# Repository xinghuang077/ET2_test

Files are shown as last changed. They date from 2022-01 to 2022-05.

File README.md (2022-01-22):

## ET2_test chip test
  - ET2_test chip test document, python code and firmware code.

  - ET2 has four circutry blocks including dedicated Inter-Integrated Circuit (I2C), Time-to-Digital Converter (TDC), Electrical Fuse (E-Fuse), and Temperature Sensor (TS). These blocks will be used in the coming ETROC2 chip. They should be fully tested and give the confidence to reuse or entend in ETROC2 chip.

## File organization
  - The repository is used to store the test document and the test code for recording and sharing. The code includes the python code communicated with I2C and the firmware for the TDC test.

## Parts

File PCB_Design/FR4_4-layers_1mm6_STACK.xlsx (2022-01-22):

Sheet: PLOECH
4-layer 搭叠， 表面处理化金5U”/镍150U”
 |  |  |  |  | SINGLE ENDED |  | EDGE COUPLED DEFFERENTIAL
Layer |  | Material | Thickness | ER | WIDTH | TARGET INPEDANCE | WIDTH | GAP | TARGET INPEDANCE
 |  | soldermask | 0.7 mil
L1 | TOP | Cu+Plating | 1.4 mil |  | 5.0 mil | 50 OHM | 4.0 mil | 7.0 mil | 100 OHM
 |  | FR4 | 3.1 mil
L2 | GND | Cu | 1.3 mil
 |  | FR4 | 50.0 mil
L3 | VCC | Cu | 1.3 mil
 |  | FR4 | 3.1 mil
L4 | BOTTOM | Cu+Plating | 1.4 mil |  | 5.0 mil | 50 OHM | 4.0 mil | 7.0 mil | 100 OHM
 |  | soldermask | 0.7 mil
 |  | Total thickness | 63.0 mil |  | 1.6mm +/- 10%
 |  |  | 1.6002

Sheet: Sheet1
8-layer 搭叠， 表面处理化金5U”/镍150U”
 |  |  |  | SINGLE ENDED |  | EDGE COUPLED DEFFERENTIAL
Layer |  | Material | Thickness | WIDTH | TARGET INPEDANCE | WIDTH | GAP | TARGET INPEDANCE
 |  | soldermask | 0.7 mil
L1 | TOP | Cu+Plating | 1.4 mil | 5 MIL | 50 OHM | 4.0 mil | 8 MIL | 100 OHM
 |  | FR4 | 3.2 mil
L2 | VCC1 | Cu | 1.2 mil
 |  | FR4 | 7.5 mil
L3 | SIG1 | Cu | 1.2 mil | 4.9 mil | 50 OHM | 4.0 mil | 8.0 mil | 100 OHM
 |  | FR4 | 7.5 mil
L4 | VCC2 | Cu | 1.2 mil
 |  | FR4 | 13.0 mil
L5 | GND | Cu | 1.2 mil
 |  | FR4 | 7.5 mil
L6 | SIG2 | Cu | 1.2 mil | 4.9 mil | 50 OHM | 4.0 mil | 8.0 mil | 100 OHM
 |  | FR4 | 7.5 mil
L7 | VCC3 | Cu | 1.2 mil
 |  | FR4 | 3.2 mil
L8 | BOTTOM | Cu+Plating | 1.4 mil | 5 MIL | 50 OHM | 4.0 mil | 8 MIL | 100 OHM
 |  | soldermask | 0.7 mil
 |  | Total thickness | 60.8 mil
4-layer 搭叠， 表面处理化金5U”/镍150U”
 |  |  |  | SINGLE ENDED |  | EDGE COUPLED DEFFERENTIAL
Layer |  | Material | Thickness | WIDTH | TARGET INPEDANCE | WIDTH | GAP | TARGET INPEDANCE
 |  | soldermask | 0.7 mil
L1 | TOP | Cu+Plating | 1.4 mil | 10 MIL | 50 OHM | 5.0 mil | 5.2 mil | 100 OHM
 |  | FR4 | 6.0 mil
L2 | GND | Cu | 1.2 mil
 |  | FR4 | 38.0 mil
L3 | VCC | Cu | 6.0 mil
 |  | FR4 | 6.0 mil
L4 | BOTTOM | Cu+Plating | 1.4 mil | 10 MIL | 50 OHM | 5.0 mil | 5.2 mil | 100 OHM
 |  | soldermask | 0.7 mil
 |  | Total thickness | 61.4 mil

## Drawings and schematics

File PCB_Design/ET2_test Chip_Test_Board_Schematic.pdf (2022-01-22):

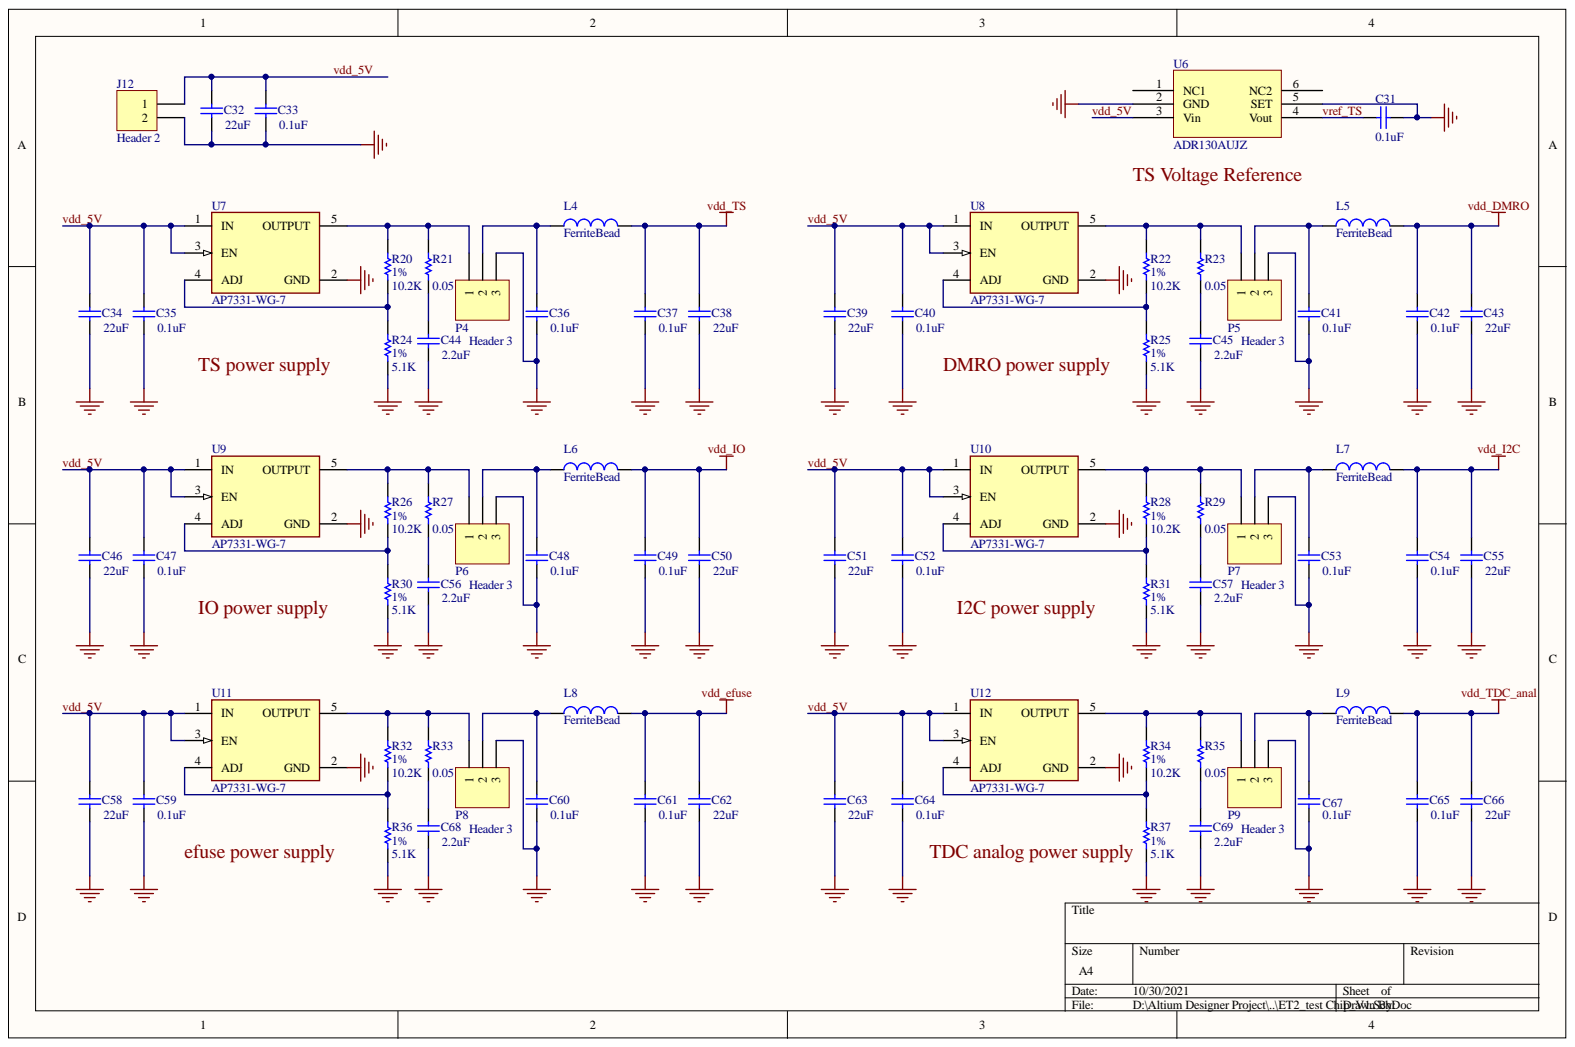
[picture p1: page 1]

Size A4 | Number | Revision

Date: 10/30/2021 | Sheet of
File: D:\Altium Designer Project\..\ET2_test Chip_V Draw1.n SBchDy: oc

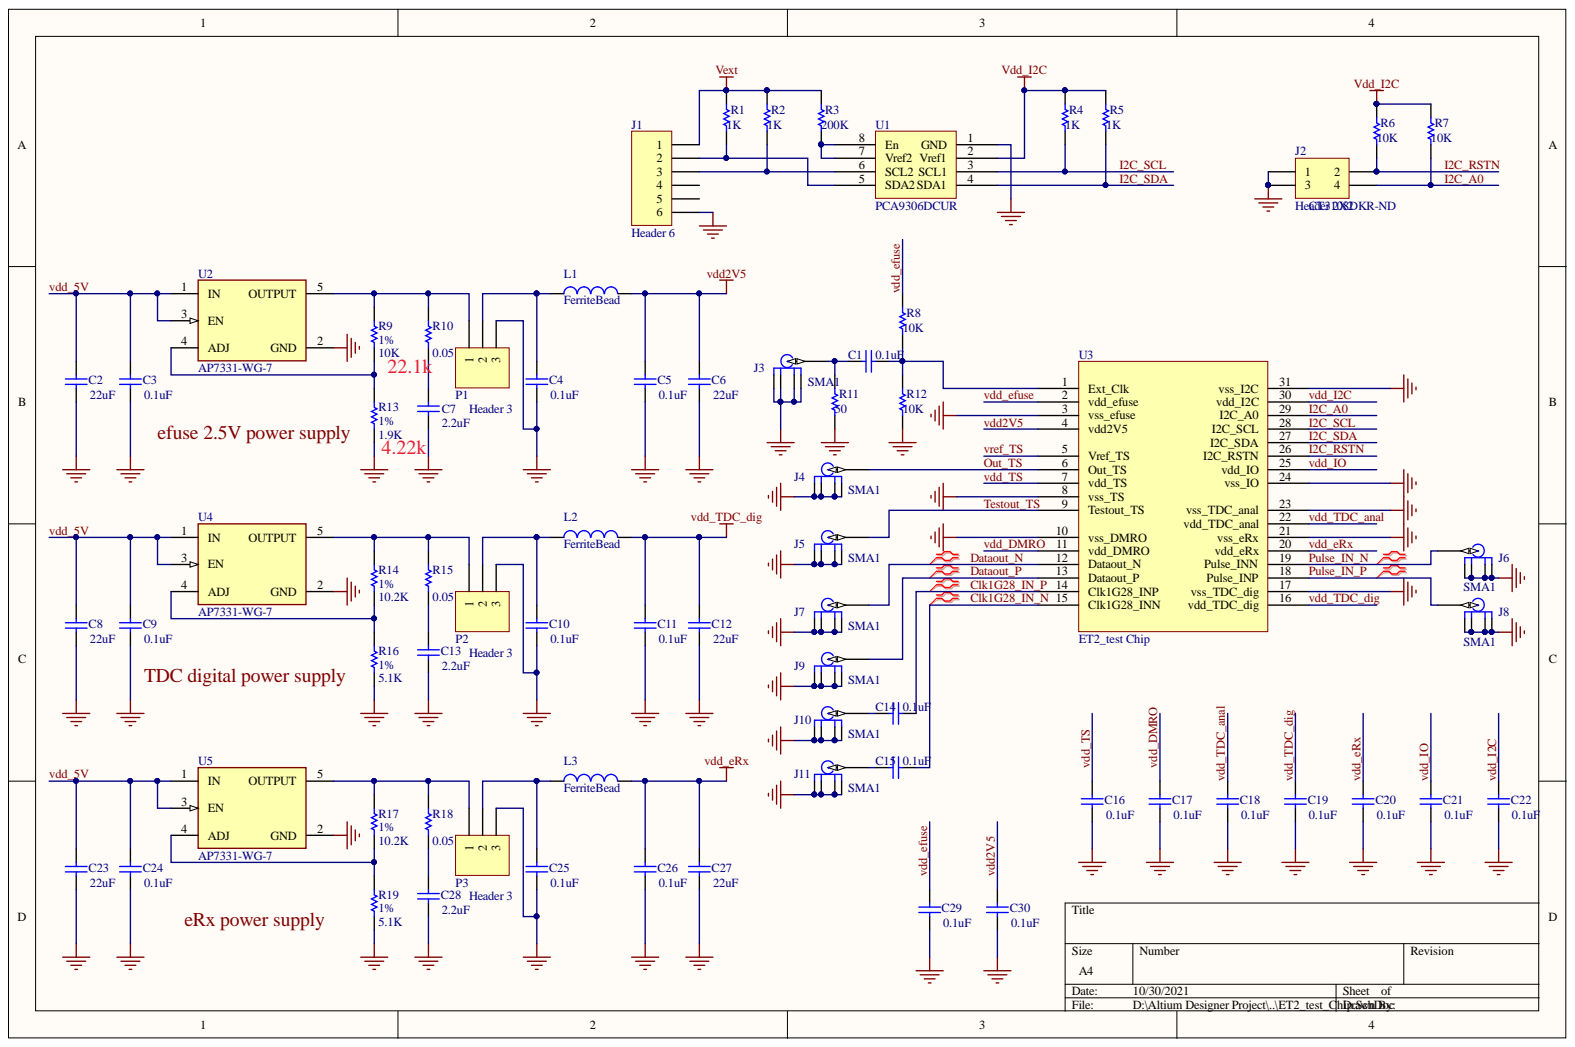
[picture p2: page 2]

Numbe r | R evision

: 10/30/2021 | She et of
File : D:\Altium D esigne r P roje ct\. .\ET2_test_Chip. Dr | aSwchDn Bocy:

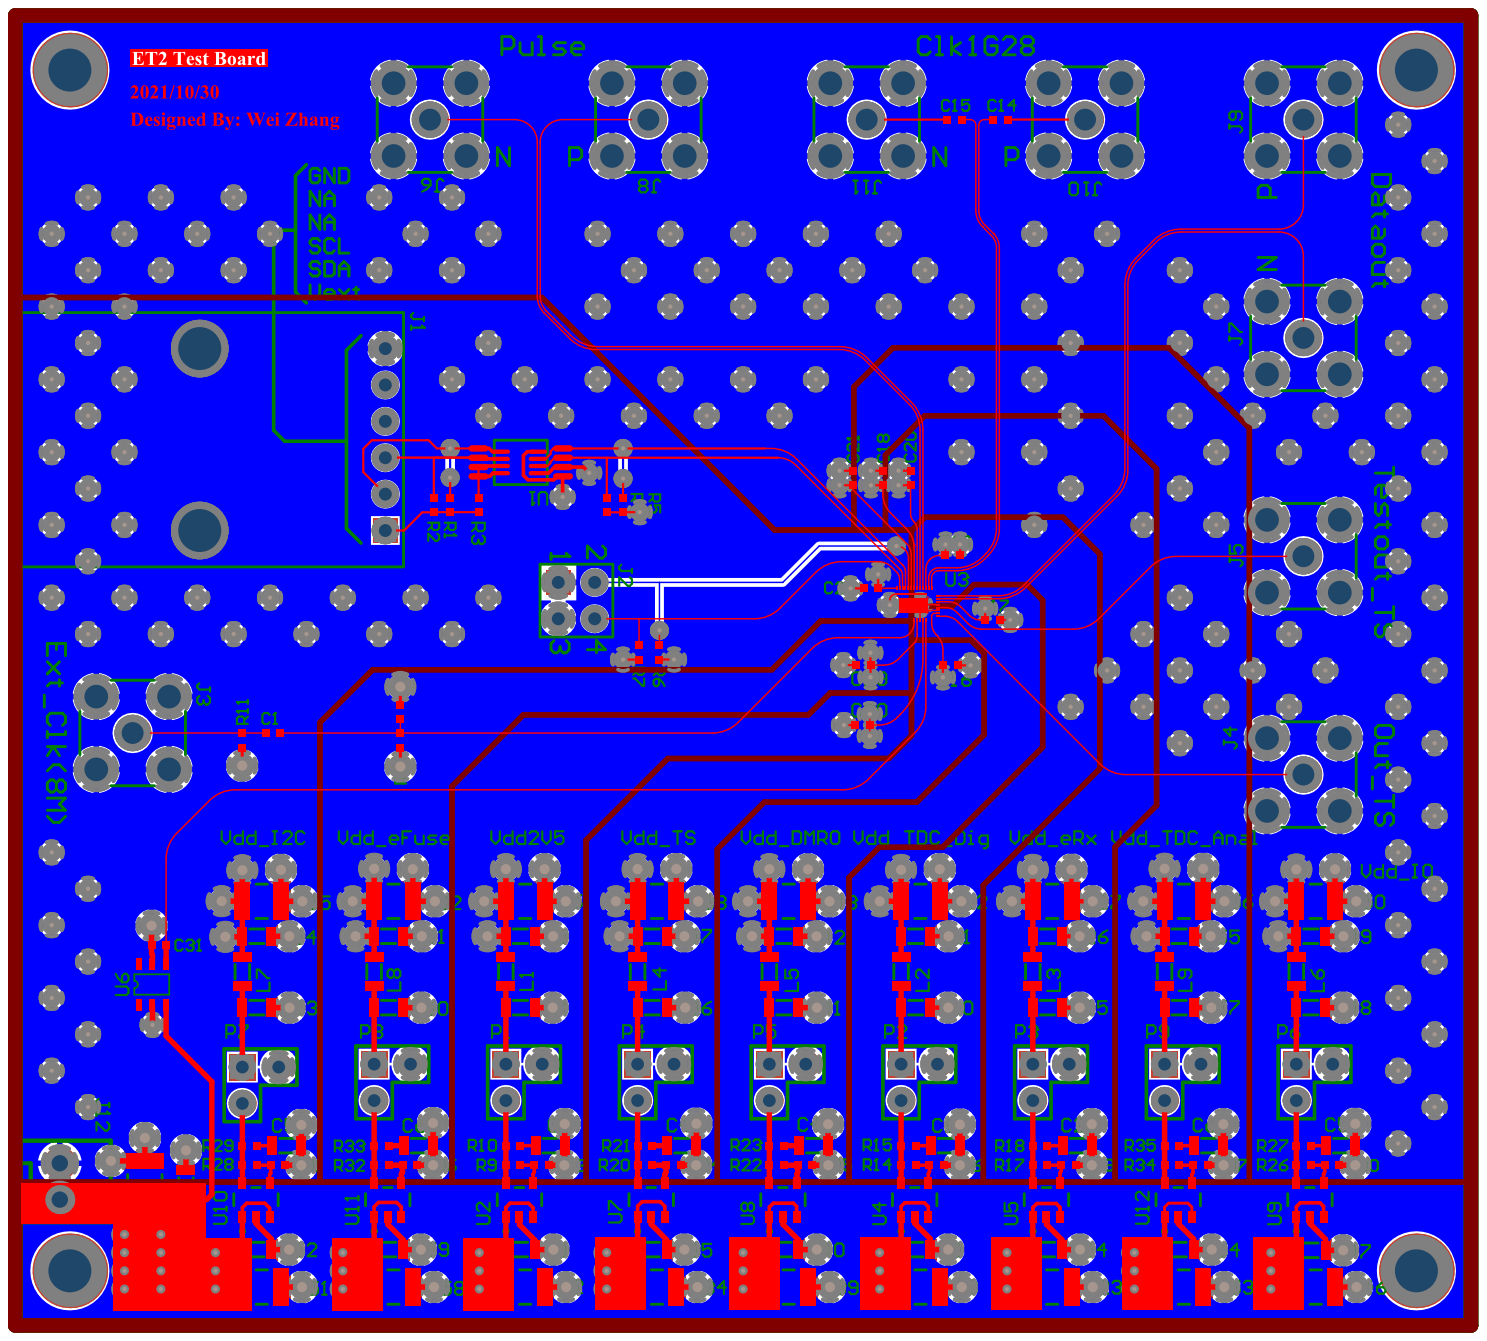
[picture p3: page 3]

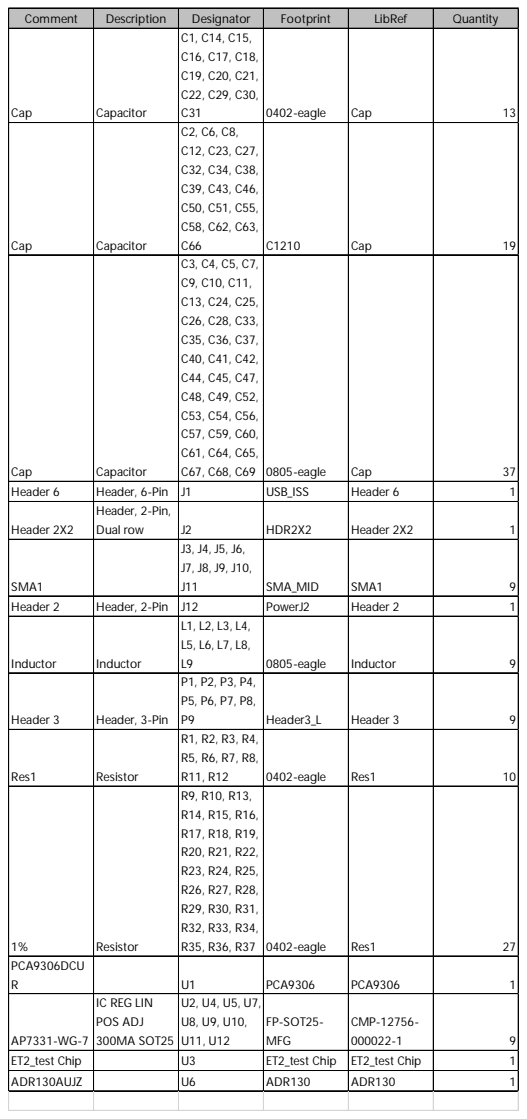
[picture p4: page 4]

Comment | Description | Designator | Footprint | LibRef | Quantity
Cap | Capacitor | C1, C14, C15, C16, C17, C18, C19, C20, C21, C22, C29, C30, C31 | 0402-eagle | Cap | 13

Cap | Capacitor | C2, C6, C8, C12, C23, C27, C32, C34, C38, C39, C43, C46, C50, C51, C55, C58, C62, C63, C66 | C1210 | Cap | 19

Cap | Capacitor | C3, C4, C5, C7, C9, C10, C11, C13, C24, C25, C26, C28, C33, C35, C36, C37, C40, C41, C42, C44, C45, C47, C48, C49, C52, C53, C54, C56, C57, C59, C60, C61, C64, C65, C67, C68, C69 | 0805-eagle | Cap | 37

Header 6 | Header, 6-Pin | J1 | USB_ISS | Header 6 | 1
Header 2X2 | Header, 2-Pin, Dual row | J2 | HDR2X2 | Header 2X2 | 1

SMA1 | | J3, J4, J5, J6, J7, J8, J9, J10, J11 | SMA_MID | SMA1 | 9

Header 2 | Header, 2-Pin | J12 | PowerJ2 | Header 2 | 1
Inductor | Inductor | L1, L2, L3, L4, L5, L6, L7, L8, L9 | 0805-eagle | Inductor | 9

Header 3 | Header, 3-Pin | P1, P2, P3, P4, P5, P6, P7, P8, P9 | Header3_L | Header 3 | 9

Res1 | Resistor | R1, R2, R3, R4, R5, R6, R7, R8, R11, R12 | 0402-eagle | Res1 | 10

1% | Resistor | R9, R10, R13, R14, R15, R16, R17, R18, R19, R20, R21, R22, R23, R24, R25, R26, R27, R28, R29, R30, R31, R32, R33, R34, R35, R36, R37 | 0402-eagle | Res1 | 27

PCA9306DCU R | | U1 | PCA9306 | PCA9306 | 1

AP7331-WG-7 | IC REG LIN POS ADJ 300MA SOT25 | U2, U4, U5, U7, U8, U9, U10, U11, U12 | FP-SOT25-MFG | CMP-12756-000022-1 | 9

ET2_test Chip | | U3 | ET2_test Chip | ET2_test Chip | 1
ADR130AUJZ | | U6 | ADR130 | ADR130 | 1

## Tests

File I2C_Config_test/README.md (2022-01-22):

USB-ISS module
-------------
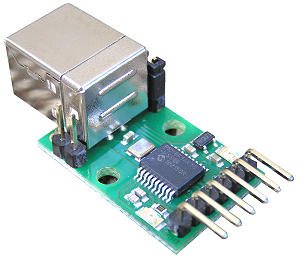
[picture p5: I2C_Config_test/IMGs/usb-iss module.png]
USB-ISS module

  - The USB-ISS  Multifunction USB Communications Module provides a complete interface between your PC and the **I2C bus**, SPI bus, a Serial port and general purpose Analogue Input or Digital I/O. The module is powered from the USB. Operating voltage is selectable between 3.3v and 5v.
  - USB-ISS document: https://www.robot-electronics.co.uk/htm/usb_iss_tech.htm
  - USB-ISS Python library: https://usb-iss.readthedocs.io
  - USB-ISS Python souce code: https://github.com/sneakypete81/usb_iss/tree/master/src/usb_iss
  - Since the operating voltage of USB-ISS module is higher than the power of ET2_test chip (1.2 V), a level translator is needed on the test PCB board to lower the logic high voltages of SDA and SCL to 1.2 V.

Usage Example
-------------
```

    from usb_iss import UsbIss, defs

    # Configure I2C mode

    iss = UsbIss()
    iss.open("COM3") # User check the PC device management for the right COM interface
    iss.setup_i2c()

    # Write and read back some data
    # NOTE: I2C methods use 7-bit device addresses (0x00 - 0x7F)
    # The example shows the register addresses is 8 bits from 0x00 to 0xFF, the USB-ISS module also support the 16-bit register addresses (0x0000 0xFFFF).
    # iss.i2c.write_ad2 for 16-bit register address writing, iss.i2c.read_ad2 for 16-bit register address reading.

    iss.i2c.write(0x62, 0, [0, 1, 2]);
    data = iss.i2c.read(0x62, 0, 3)

    print(data)
    # [0, 1, 2]
```

Installing
----------
```
    pip install usb-iss

```

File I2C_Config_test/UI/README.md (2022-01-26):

PyQt5 is a comprehensive set of Python bindings for Qt v5. PyQt5 is the latest version of a GUI widgets toolkit developed by Riverbank Computing. It is a Python interface for Qt, one of the most powerful, and popular cross-platform GUI library.

https://pypi.org/project/PyQt5/

https://www.tutorialspoint.com/pyqt5/index.htm

PyQt5 is selectd to implement UIs for different ET2_test test purposes.
This is an example for ET2_test I2C test. The simple thing is read or write one byte at one time.

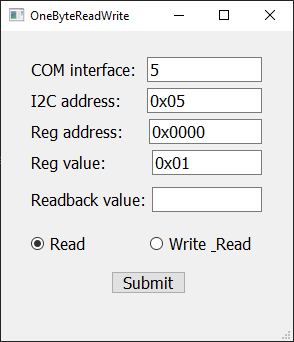
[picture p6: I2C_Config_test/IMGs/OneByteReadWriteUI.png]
ET2_test onebytereadwriteUI


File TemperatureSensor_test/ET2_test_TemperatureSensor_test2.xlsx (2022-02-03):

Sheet: Sheet1
TempSetting | TS_testOUT4 | TS_OUT4 | TS_testOUT5 | TS_OUT5 | TS_testOUT6 | TS_OUT6 | TS_testOUT7 | TS_OUT7 | TS_testOUT8 | TS_OUT8 | PT100
25 | 0.5389 | 0.5441 | 0.6075 | 0.6141 | 0.5412 | 0.5459 | 0.567 | 0.5725 | 0.496 | 0.4999 | 109.599
30 | 0.5516 | 0.5566 | 0.6211 | 0.6275 | 0.5563 | 0.5615 | 0.5803 | 0.5858 | 0.5095 | 0.5133 | 111.726
35 | 0.565 | 0.5703 | 0.6354 | 0.6426 | 0.573 | 0.5782 | 0.5944 | 0.5997 | 0.5237 | 0.5275 | 113.991
40 | 0.5778 | 0.5831 | 0.6486 | 0.6557 | 0.5874 | 0.5925 | 0.608 | 0.6136 | 0.5375 | 0.5414 | 116.092
45 | 0.5864 | 0.5923 | 0.6395 | 0.6463 | 0.5807 | 0.5855 | 0.621 | 0.6268 | 0.5499 | 0.5536 | 118.15
50 | 0.6 | 0.6056 | 0.653 | 0.6599 | 0.5954 | 0.601 | 0.6344 | 0.6401 | 0.5634 | 0.5675 | 120.295
55 | 0.612 | 0.6177 | 0.6666 | 0.6734 | 0.6103 | 0.6154 | 0.6481 | 0.6535 | 0.5768 | 0.5811 | 122.326
60 | 0.6244 | 0.6301 | 0.6784 | 0.6852 | 0.6244 | 0.6298 | 0.661 | 0.6672 | 0.591 | 0.5949 | 124.463
65 | 0.6372 | 0.6431 | 0.6914 | 0.6983 | 0.638 | 0.6439 | 0.6742 | 0.6807 | 0.604 | 0.6082 | 126.574
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

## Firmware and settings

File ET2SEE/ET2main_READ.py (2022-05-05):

# import pandas as pdc
import os
import pyvisa as visa
import sys
import time
from usb_iss import UsbIss, defs
import ET2_test_functions
import numpy as np
import datetime

'''
@author: Xing Huang
@date: Jan. 7, 2021
This script as a generic I2C cofniguration software to configure I2C slave. The I2C reg configuration data is read into a xxx.dat file.
The UsbIss as I2C master deivce is used to write and read I2C slave register.
'''


#-----------------------------------------------------------------------------------#
freqency = 1000
duration = 200
#-----------------------------------------------------------------------------------#
def main():
    user_config_filename = "ET2_Config_SEUTest.txt" ## ET2_Config_SEUTest modified the line 520, 521 for SEU test based on ET2_Config.txt
    COM_Port = "COM4"
    
    # value = input("Please enter the number of the ET2_test board you are testing:\n")

    ## All of the register addresses, and default values 
    Reg_Addr = []
    Reg_Val_Default = []
    Reg_Val_Write = []
    Reg_Val_Broadcast = []      

    ## Read configuraton file, I2C address, 16-bit register addresses, 8-bit register values
    with open(user_config_filename, 'r') as infile:                  # read configuration file
        for line in infile.readlines():
            if len(line.split()) == 1:
                #print(len(line.split()))                          # read I2C address
                I2C_Addr = int(line.split()[0], 16)
            else:                                               # read register address and value
                Reg_Addr += [int(line.split()[0], 16)]
                Reg_Val_Default += [int(line.split()[1], 16)]
                Reg_Val_Write += [int(line.split()[2], 16)]
                Reg_Val_Broadcast += [int(line.split()[3], 16)]
    print('There are', len(Reg_Addr), 'registers in ET2_test chip.')

    ## Power Supply USB devices
    VISA_ADDRESS = ET2_test_functions.find('USB?*INSTR')

    ## set usb-iss iic master device
    iss = UsbIss()
    iss.open(COM_Port)
    iss.setup_i2c(clock_khz=100)

    ## Check whether a device responds at the specified I2C address.
    if(not iss.i2c.test(I2C_Addr)):
        print("Unsuccessful communication with the target via I2C!")
        return
    print("Successful communication with the target via I2C!")

    ## Swap all register addresses in ET2_test chip.
    Reg_Addr_new = ET2_test_functions.regAddrSwap(Reg_Addr)
    # print("reg addr swapped") 
     

    while True:
       ###################################################################################################### 
       # Pixel configuration registers write and read back to compare the write-in and read-back values
       ######################################################################################################
        myAddr = []
        myreadVal = []              
        expectedVal = []
        for i in list(range(0, 8)) + list(range(120, 128)) + list(range(128, 136)) + list(range(248, 256)) + list(range(512, 524)):
            myAddr += [Reg_Addr[i]]
            expectedVal += [Reg_Val_Write[i]]
            myreadVal += iss.i2c.read_ad2(I2C_Addr, Reg_Addr_new[i], 1) 
            # print("%d %x %x" %(i, Reg_Addr[i], Reg_Val_Write[i]))
        #end for

       ######################################################################################################
       ## SEU Counter Read
       ######################################################################################################
        seuCntAddr = []
        seuCntVal = []
        for i in list(range(560, 564)):
            seuCntAddr += [Reg_Addr[i]]
            # print(hex(Reg_Addr[i]))
            seuCntVal += iss.i2c.read_ad2(I2C_Addr, Reg_Addr_new[i], 1) 
        # print("%s" %( lasttime), "SEU counter Addresses:", '[{}]'.format(', '.join(hex(x) for x in seuCntAddr)), "Values:", "%s" %( serCntVal))
        # print("%s The SEU counter in ET2_test I2C, address & value %s %s" %(lasttime, seuCntAddr, serCntVal))
        #end for


       ######################################################################################################
       ## Variable Status Read
       ######################################################################################################
        statusVarAddr = []
        statusVarReadVal = []              
        statusVarExpectedVal = []
        for i in list(range(256, 264)) + list(range(376, 392)) +  list(range(504, 512)):
        # for i in list(range(504, 512)):
            # print(hex(Reg_Addr[i]))
            statusVarAddr += [Reg_Addr[i]]
            # statusVarExpectedVal += [Reg_Val_Default[i]]
            statusVarReadVal += iss.i2c.read_ad2(I2C_Addr, Reg_Addr_new[i], 1) 
            # print("%d %x %x" %(i, Reg_Addr[i], Reg_Val_Write[i]))
            
        statusVarExpectedVal = []
        regAddr = []
        regReadVal = []
        for i in list(range(0, 8)) + list(range(120, 128)) + list(range(128, 136)) + list(range(248, 256)) + list(range(512, 520)):
            regAddr += [Reg_Addr[i]]
            regReadVal += iss.i2c.read_ad2(I2C_Addr, Reg_Addr_new[i], 1)
        # print(regReadVal[0], statusVarReadVal[0])
        statusVarExpectedVal = [regReadVal[0] ^ 0x00,  regReadVal[1] ^ 0xff,  regReadVal[2] ^ 0xff,  regReadVal[3] ^ 0xff, \
                                regReadVal[4] ^ 0xff,  regReadVal[5] ^ 0xff,  regReadVal[6] ^ 0xff,  regReadVal[7] ^ 0xff, \
                                regReadVal[8] ^ 0x0f,  regReadVal[9] ^ 0xff,  regReadVal[10] ^ 0xff, regReadVal[11] ^ 0xff, \
                                regReadVal[12] ^ 0xff, regReadVal[13] ^ 0xff, regReadVal[14] ^ 0xff, regReadVal[15] ^ 0xff, \
                                regReadVal[16] ^ 0xf0, regReadVal[17] ^ 0xff, regReadVal[18] ^ 0xff, regReadVal[19] ^ 0xff, \
                                regReadVal[20] ^ 0xff, regReadVal[21] ^ 0xff, regReadVal[22] ^ 0xff, regReadVal[23] ^ 0xff, \
                                regReadVal[24] ^ 0xff, regReadVal[25] ^ 0xff, regReadVal[26] ^ 0xff, regReadVal[27] ^ 0xff, \
                                regReadVal[28] ^ 0xff, regReadVal[29] ^ 0xff, regReadVal[30] ^ 0xff, regReadVal[31] ^ 0xff]
        # print(statusVarExpectedVal, "\n", statusVarReadVal) 
    

       ######################################################################################################
       ## Stasus Read
       ######################################################################################################
        statusAddr = []
        statusReadVal = []              
        statusExpectedVal = []
        for i in list(range(8, 120)) + list(range(136, 248)) + list(range(264, 376)) +  list(range(392, 504)):
            statusAddr += [Reg_Addr[i]]
            statusExpectedVal += [Reg_Val_Default[i]]
            statusReadVal += iss.i2c.read_ad2(I2C_Addr, Reg_Addr_new[i], 1) 
            # print("%d %x %x" %(i, Reg_Addr[i], Reg_Val_Write[i]))


       ######################################################################################################
       ## E-Fuse Read
       ######################################################################################################
        ## efuse config registers
        efuseConfigAddr = []
        efuseConfigWrite = []
        efuseConfigRead = []
        for i in list(range(518, 520)):
            # print(hex(Reg_Addr[i]))
            efuseConfigAddr += [Reg_Addr_new[i]]
            efuseConfigWrite += [Reg_Val_Default[i]]
            efuseConfigRead += iss.i2c.read_ad2(I2C_Addr, Reg_Addr_new[i], 1)  
            
        efMode = 0b10                   # 0b10 read mode, 0b01 write mode
        tsPD = 0b0
        dataOut_disBias = 0b0
        dataOut_AmpSel = 0b111
        dataOut_Sel = 0b1

        efTckhp = 0b0100                # 4'b0100 ~ 5 us
        efStart = 0b0                  # start = 1
        efClkSel = 0b0
        efClkEn = 0b1
        efRstN = 0b1
        # efProg_preDef = 0x0000_0000     #32'h0001
        Reg6 = (efMode << 6) + (tsPD << 5) +(dataOut_disBias << 4) +(dataOut_AmpSel <<1) + (dataOut_Sel)
        Reg7 = (efTckhp << 4) + (efStart << 3) + (efClkSel << 2) + (efClkEn << 1) + efRstN
    
        ##0. Write the initialization of eFuse configuration registers.
        # iss.i2c.write_ad2(I2C_Addr, efuseConfigAddr[0], [Reg6, Reg7])
        # print('[{}]'.format(', '.join(hex(x) for x in iss.i2c.read_ad2(I2C_Addr, efuseConfigAddr[0], 2))))
        ##1. Reset the eFuse after the initialization.
        efRstN = 0b0 # reset = 0
        Reg7 = (efTckhp << 4) + (efStart << 3) + (efClkSel << 2) + (efClkEn << 1) + efRstN
        iss.i2c.write_ad2(I2C_Addr, efuseConfigAddr[1], [Reg7])    
        efRstN = 0b1 # reset = 1
        Reg7 = (efTckhp << 4) + (efStart << 3) + (efClkSel << 2) + (efClkEn << 1) + efRstN
        iss.i2c.write_ad2(I2C_Addr, efuseConfigAddr[1], [Reg7])
        ##2. Write start a pulse to generate the falling edge.
        efStart = 0b0 # start = 0
        Reg7 = (efTckhp << 4) + (efStart << 3) + (efClkSel << 2) + (efClkEn << 1) + efRstN
        iss.i2c.write_ad2(I2C_Addr, efuseConfigAddr[1], [Reg7]) 
        efStart = 0b1 # start = 1
        Reg7 = (efTckhp << 4) + (efStart << 3) + (efClkSel << 2) + (efClkEn << 1) + efRstN
        iss.i2c.write_ad2(I2C_Addr, efuseConfigAddr[1], [Reg7]) 
        efStart = 0b0 # start = 0
        Reg7 = (efTckhp << 4) + (efStart << 3) + (efClkSel << 2) + (efClkEn << 1) + efRstN
        iss.i2c.write_ad2(I2C_Addr, efuseConfigAddr[1], [Reg7])   
        ##3. After writing the eFuse, read back the values of eFuse.
        # Registers' addresses are 0x0100, 0x0101, 0x0102, 0x0103.        
        efuseReadVal = []              
        efuseExpectedVal = []
        ## Registers stored the efule values
        for i in list(range(572, 576)):
            # print(hex(Reg_Addr[i]))
            efuseExpectedVal += [Reg_Val_Write[i]]
            efuseReadVal += iss.i2c.read_ad2(I2C_Addr, Reg_Addr_new[i], 1)
        # print('[{}]'.format(', '.join(hex(x) for x in efuseExpectedVal)),\
        #       '[{}]'.format(', '.join(hex(x) for x in efuseReadVal)))
        # print(efuseExpectedVal, efuseReadVal)
        ##Rewrite the Reg6/Reg7 to the write value
        # iss.i2c.write_ad2(I2C_Addr, 0x0600, [0xDC])
        # iss.i2c.write_ad2(I2C_Addr, 0x0700, [0xFE])        


       ######################################################################################################
       ## Power Supply Source Current Read
       ######################################################################################################
        ## Change this variable to the address of your instrument
        # VISA_ADDRESS = 'USB0::0x2A8D::0x1102::MY58041593::INSTR'
                # print(VISA_ADDRESS)
        try:
            ## Create a connection (session) to the instrument
            resourceManager = visa.ResourceManager()
            session = resourceManager.open_resource(VISA_ADDRESS)    # connect to SOC
            # print(session.query("*IDN?"))
        except visa.Error as ex:
            print('Couldn\'t connect to \'%s\', exiting now...' % VISA_ADDRESS)
            sys.exit()
        # session.write("SOURce:VOLTage %.3f,(@1)"%(1.2))                         # Channel One Power Voltage Setting
        current_Ch1 = round(float(session.query("MEAS:CURR? CH1"))*1000000.0, 3)   # Channel One Current Reading
        # ## Close the connection to the instrument
        # session.close()
        # resourceManager.close()
       
       
       ######################################################################################################
       ## Info Printing and Output to txt file
       ######################################################################################################
        with open("./DATA/ET2_I2C_EFUSE_register.TXT", 'a') as infile_iic:  
            lasttime = datetime.datetime.now()
            if expectedVal == myreadVal :
                print("%s \nI2C Written == Read: %s\nSEU counter values:%s\n" % (lasttime, '[{}]'.format(', '.join(hex(x) for x in myreadVal)), '[{}]'.format(', '.join(hex(x) for x in seuCntVal))))
                infile_iic.write("%s \nI2C Written == Read: %s\nSEU counter values:%s\n" % (lasttime, '[{}]'.format(', '.join(hex(x) for x in myreadVal)), '[{}]'.format(', '.join(hex(x) for x in seuCntVal))))
            else:
                print("%s \nI2C Written != Read: %s\nSEU counter values:%s\n" % (lasttime, '[{}]'.format(', '.join(hex(x) for x in myreadVal)), '[{}]'.format(', '.join(hex(x) for x in seuCntVal))))
                infile_iic.write("%s \nI2C Written != Read: %s\nSEU counter values:%s\n" % (lasttime, '[{}]'.format(', '.join(hex(x) for x in myreadVal)), '[{}]'.format(', '.join(hex(x) for x in seuCntVal))))
            # end if mywriteval == myreadval

            if statusVarExpectedVal == statusVarReadVal :
                print("I2C Variable Status Expected == Read: %s\n" % ('[{}]'.format(', '.join(hex(x) for x in statusVarReadVal))))
                infile_iic.write("I2C Variable Status Expected == Read: %s\n" % ('[{}]'.format(', '.join(hex(x) for x in statusReadVal))))
            else:
                print("I2C Variable Status Expected != Read: %s\n" % ('[{}]'.format(', '.join(hex(x) for x in statusVarReadVal))))
                infile_iic.write("I2C Variable Status Default != Read: %s\n" % ('[{}]'.format(', '.join(hex(x) for x in statusReadVal))))
            # end if statusVarExpectedVal == statusVarReadVal

            if statusExpectedVal == statusReadVal :
                print("I2C Fixed Status Default == Read: %s\n" % ('[{}]'.format(', '.join(hex(x) for x in statusReadVal))))
                infile_iic.write("I2C Fixed Status Default == Read: %s\n" % ('[{}]'.format(', '.join(hex(x) for x in statusReadVal))))
            else:
                print("I2C Fixed Status Default != Read: %s\n" % ('[{}]'.format(', '.join(hex(x) for x in statusReadVal))))
                infile_iic.write("I2C Fixed Status Default != Read: %s\n" % ('[{}]'.format(', '.join(hex(x) for x in statusReadVal))))
            # end if statusExpectedVal == statusReadVal
                
            if efuseExpectedVal == efuseReadVal :
                print("E-Fuse values of B1/9 Expected == Read: %s\n" % ('[{}]'.format(', '.join(hex(x) for x in efuseReadVal))))
                infile_iic.write("E-Fuse values of B1/9 Expected == Read: %s\n" % ('[{}]'.format(', '.join(hex(x) for x in efuseReadVal))))
            else:
                print("E-Fuse values of B1/9 Expected != Read: %s\n" % ('[{}]'.format(', '.join(hex(x) for x in efuseReadVal))))
                infile_iic.write("E-Fuse values of B1/9 Expected != Read: %s\n" % ('[{}]'.format(', '.join(hex(x) for x in efuseReadVal))))
            # end if efuseExpectedVal == efuseReadVal
            infile_iic.flush()
        # end with
                      
        with open("./DATA/ET2_I2C_EFUSE_current.TXT", 'a') as infile_current:  
            lasttime = datetime.datetime.now()
            print("%s %d uA\n" % (lasttime, current_Ch1))
            infile_current.write("%s %d uA\n" % (lasttime, current_Ch1) )
        # end with

        time.sleep(15) 
    # end while 
# end def main

#-----------------------------------------------------------------------------------#
if __name__ == '__main__':
    main()

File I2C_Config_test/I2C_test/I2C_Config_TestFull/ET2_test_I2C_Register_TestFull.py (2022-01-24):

# import pandas as pdc
import os
import sys
import time
import winsound
from usb_iss import UsbIss, defs
import ET2_test_functions

import numpy as np

'''
@author: Xing Huang
@date: Jan. 7, 2021
This script as a generic I2C cofniguration software to configure I2C slave. The I2C reg configuration data is read into a xxx.dat file.
The UsbIss as I2C master deivce is used to write and read I2C slave register.
'''


#-----------------------------------------------------------------------------------#
freqency = 1000
duration = 200
#-----------------------------------------------------------------------------------#
def main():
    ''' I2C test ''' 

    user_config_filename = "ET2_test_I2C_Config_Configuration_FullRW_V3.txt" 

    COM_Port = "COM10"

    # All of the register addresses, and default values 
    Reg_Addr = []
    Reg_Val_Default = []
    Reg_Val_Write = []
    Reg_Val_Broadcast = []      

    # Read configuraton file, I2C address, 16-bit register addresses, 8-bit register values
    with open(user_config_filename, 'r') as infile:                  # read configuration file
        for line in infile.readlines():
            if len(line.split()) == 1:
                #print(len(line.split()))                          # read I2C address
                I2C_Addr = int(line.split()[0], 16)
            else:                                               # read register address and value
                Reg_Addr += [int(line.split()[0], 16)]
                Reg_Val_Default += [int(line.split()[1], 16)]
                Reg_Val_Write += [int(line.split()[2], 16)]
                Reg_Val_Broadcast += [int(line.split()[3], 16)]

    print('There are', len(Reg_Addr), 'registers in ET2_test chip.')

    # set usb-iss iic master device
    iss = UsbIss()
    iss.open(COM_Port)
    iss.setup_i2c(clock_khz=100)

    # Check whether a device responds at the specified I2C address.
    if(iss.i2c.test(I2C_Addr)):
        # print("Successful communication with the target via I2C!")
        winsound.PlaySound("SystemExit", winsound.MB_OK)
        print('-------------------------I2C Successful Communication---------------------------')


        #Swap all register addresses in ET2_test chip.
        Reg_Addr_new = ET2_test_functions.regAddrSwap(Reg_Addr)

        # All of the pixel and common-circuit configuration and status registers, read back the default values
        Reg_Addr_Read = []
        Reg_Val_Read_Default = []
        read_data = []
        for i in range(len(Reg_Addr)):              # read data from i2c slave
            if ((i < 564) & (i != 544) & (i != 545) & (i != 546)  & (i != 547) & (i != 559)):
                Reg_Addr_Read += [Reg_Addr[i]]
                Reg_Val_Read_Default += [Reg_Val_Default[i]]
                read_data += iss.i2c.read_ad2(I2C_Addr, Reg_Addr_new[i], 1)
        print("STEP 1: Read back all the registers' default values, and compare:")
        defaultMatch = ET2_test_functions.valueCompare(Reg_Addr, Reg_Val_Read_Default, read_data) == 1
        if(defaultMatch == 1):
            print('ET2_test I2C Registers Default Values Read Test Passed!')
        else:
            print('ET2_test I2C Registers Default Values Read Test Failed!')
        print('----------------------------------STEP1 END-------------------------------------')


        # defaultMatch = 0
        # if(defaultMatch == 1):
        if(defaultMatch == 1):
            for i in range(len(Reg_Addr)):
                if((0 <= i <=255) | (512 <= i <= 563)):
                    iss.i2c.write_ad2(I2C_Addr, Reg_Addr_new[i], [Reg_Val_Write[i]])


            # Pixel configuration registers write and read back to compare the write-in and read-back values
            Reg_Addr_pixConfigurable = []
            Reg_Val_Write_pixConfigurable = []              
            read_data_writeTest_pixConfigurable = []
            for i in range(len(Reg_Addr)):
                if ((0 <= i <= 7) | (120 <= i <= 135) | (248 <= i <= 255)):
                    Reg_Addr_pixConfigurable += [Reg_Addr[i]]
                    Reg_Val_Write_pixConfigurable += [Reg_Val_Write[i]]
                    read_data_writeTest_pixConfigurable += iss.i2c.read_ad2(I2C_Addr, Reg_Addr_new[i], 1)
            print("STEP2: Write and Read back the pixel configuration registers' default values, and compare:")
            if (ET2_test_functions.valueCompare(Reg_Addr_pixConfigurable, Reg_Val_Write_pixConfigurable, read_data_writeTest_pixConfigurable) == 1):
                print('Pixel Configurable Registers Write and Read Test Passed!')
            else:
                print('Pixel Configurable Registers Write and Read Test Failed!')
            print('----------------------------------STEP2 END-------------------------------------')


            # Common-circuit configuration registers write and read back to compare the write-in and read-back values
            Reg_Addr_comConfig = []
            Reg_Val_Write_comConfig = []              
            read_data_writeTest_comConfig = []
            for i in range(len(Reg_Addr)):
                if (512 <= i <= 543):
                    Reg_Addr_comConfig += [Reg_Addr[i]]
                    Reg_Val_Write_comConfig += [Reg_Val_Write[i]]
                    read_data_writeTest_comConfig += iss.i2c.read_ad2(I2C_Addr, Reg_Addr_new[i], 1)
                    # print(i, hex(Reg_Addr[i]))
            print("STEP3: Write and Read back the Common-circuit configuration registers' default values, and compare:")
            if (ET2_test_functions.valueCompare(Reg_Addr_comConfig, Reg_Val_Write_comConfig, read_data_writeTest_comConfig) == 1):
                print('Common-circuit Configuration Registers Write and Read Test Passed!')
            else:
                print('Common-circuit Configuration Registers Write and Read Test Failed!')
            print('----------------------------------STEP3 END-------------------------------------')
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

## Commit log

2022-01-24 Add PCB design descriptions
2022-01-26 I2C one byte write and read ui
2022-05-05 Add files via upload
    SEE test code
    [ET2_Config_SEUTest.txt]
2022-05-05 Update ET2_Config_SEUTest.txt
    Register map file, addresses, default, and writing values
    [ET2_Config_SEUTest.txt]
2022-05-05 Register map file, addresses and values
    [ET2_Config_SEUTest.txt]
2022-05-05 Recording all the current @ ch1.
2022-05-05 Recording all the current at channel 1.
2022-05-05 Add the power supply USB address autofill.
